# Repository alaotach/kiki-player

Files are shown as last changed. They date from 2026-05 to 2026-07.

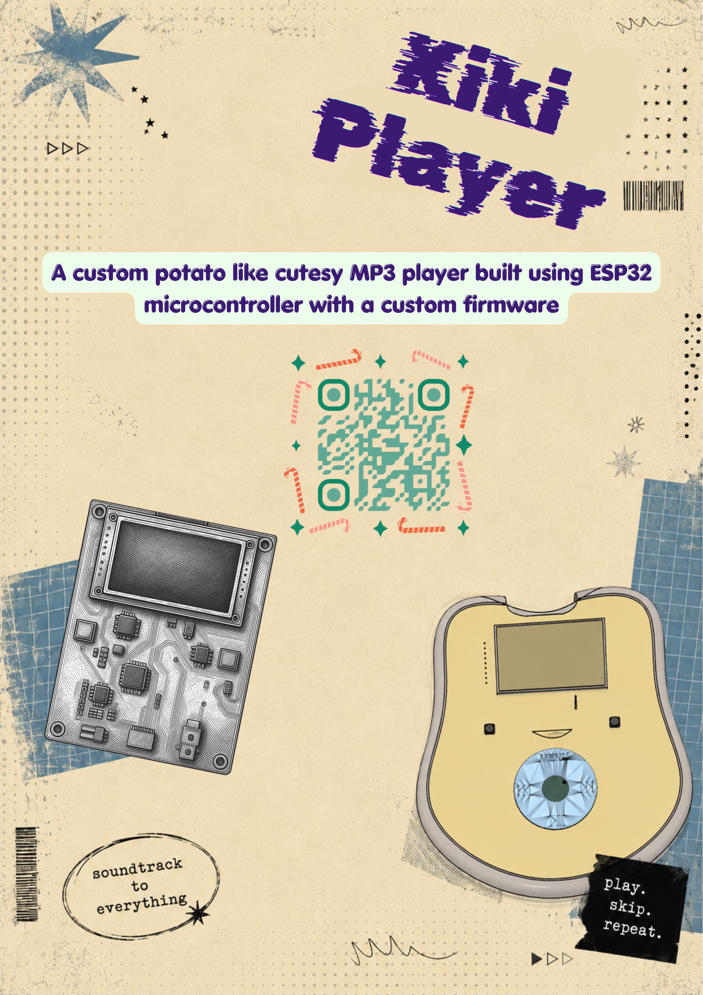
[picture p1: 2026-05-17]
docs/Blue and Pink Modern Film Poster.png

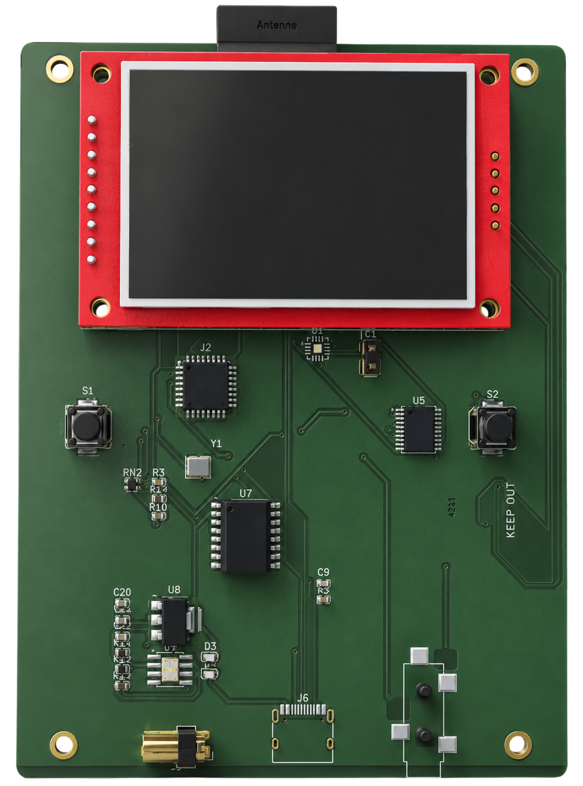
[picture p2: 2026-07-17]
assets/pcb-render.png.png

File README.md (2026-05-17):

# Kiki-Player

## Project Overview

So basically this whole thing was built for a program by hackclub named fallout and I got an idea to build an mp3 player to replace spotify like good old times from a random youtube video titled "how to quit spotify" and I actually managed to pull it off. It's a fully custom PCB including a 3D case that plays music, has a touch sensitive click wheel.

Zine

## What's Inside This Folder

**PCB Files:**
- `kiki-player.kicad_sch` - The main schematic where everything's connected.
- `kiki-player.kicad_pcb` - The actual PCB layout with all components placed and routed.
- `Sample-BOM_JLCSMT.xlsx` - Bill of Materials with all the parts.

**Firmware:**
- `kiki-player/` - It has all the firmware source code written in arduino with platformIo.

**3D Case Files:**
- `kiki-player-B_Cu.glb` / `kiki-player-B_Mask.glb` / `kiki-player-F_CuGlr` etc. - These are the individual layer exports from KiCad.
- `updated-pcb.step` - The 3D model of the PCB itself that I imported into Fusion 360 to design the case around it
- `kiki-player-case.stl` - The 3D model of the PCB case.

**Misc Files:**
- `.gorjob` files - Job queue files from Fusion 360 (not super important)
- `.csv` files - Component positioning data and BOM exports

## The Files You Actually Need

**To Manufacture the PCB:**
1. `kiki-player.kicad_pcb` - Send this to JLCPCB (export as gerbers first)
2. `Sample-BOM_JLCSMT.xlsx` - Upload this with your PCB order for parts + assembly
3. `kiki-player.kicad_sch` - Reference schematic if anything goes wrong

**For Reference:**
- `kiki-player.kicad_pro` - Open this in KiCad if you want to modify anything
- Schematic files - Check these if you want to understand how everything's wired

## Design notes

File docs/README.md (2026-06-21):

# Kiki-Player
## Project Overview
So basically this whole thing was built for a program by hackclub named fallout and I got an idea to build an mp3 player to replace spotify like good old times from a random youtube video titled "how to quit spotify" and I actually managed to pull it off. It's a fully custom PCB including a 3D case that plays music, has a touch sensitive click wheel.
zine-kikii

## What's Inside This Folder
**PCB Files:**
- `kiki-player.kicad_sch` - The main schematic where everything's connected.
- `kiki-player.kicad_pcb` - The actual PCB layout with all components placed and routed.
- `Sample-BOM_JLCSMT.xlsx` - Bill of Materials with all the parts.

**Firmware:**
- `kiki-player/` - It has all the firmware source code written in arduino with platformIo.

**3D Case Files:**
- `kiki-player-B_Cu.glb` / `kiki-player-B_Mask.glb` / `kiki-player-F_CuGlr` etc. - These are the individual layer exports from KiCad.
- `pcb.step` - The 3D model of the PCB itself that I imported into Fusion 360 to design the case around it
- 
- `kiki-player-case.step` - The 3D model of the PCB case.
kiki-case-1
kiki-case-2

**Misc Files:**
- `.csv` files - Component positioning data and BOM exports
- 

## The Files You Actually Need
**To Manufacture the PCB:**
1. `kiki-player.kicad_pcb` - Send this to JLCPCB
2. `Sample-BOM_JLCSMT.xlsx` - Upload this with your PCB order for parts + assembly
3. `kiki-player.kicad_sch` - Reference schematic if anything goes wrong

**For Reference:**
- `kiki-player.kicad_pro` - Open this in KiCad if you want to modify anything
---

## Build Guide

### Step 1 - Export Gerbers from KiCad

open `kiki-player.kicad_pcb` in KiCad, then go to **File → Fabrication Outputs → Gerbers**. In the dialog, make sure all layers are checked and hit Generate. Then go back to **File → Fabrication Outputs → Drill Files** and generate those too. Put everything in one folder and zip it up.

---

### Step 2 - Order the PCB from JLCPCB

Go to jlcpcb and upload your gerber zip.

- Then enable PCBA and upload `Sample-BOM_JLCSMT.xlsx` as the BOM and `kiki-player-all-pos.csv` as the component placement file.
---

### Step 3 - Prepare the SD Card

Format a MicroSD card as FAT32 and dump MP3 files into it.

---

### Step 4 - Solder the TH Parts

- **J5** - 2-pin JST PH2.0 MALE Connector - connects to battery lipo
- **LS1** - 2-pin JST PH2.0 MALE Connector - connects to speaker
- **J3** - 3.5mm audio jack
---

### Step 5 - Connect the Battery

Get a 1000mAh flat LiPo with a 2-pin JST PH2.0 connector.
---

### Step 6 - Connect the Display

- The ILI9341 display module connects via a ribbon cable.
---

### Step 7 - Flash the Firmware

```bash
cd firmware/kiki-player
pio run --target upload
```
( You need VSCode and PlatformIO for it )

### Step 8 - 3D Print and Assemble the Case
- **Material:** PLA works fine.

When everything fits, seat the PCB, connect the display ribbon, tuck the battery into the remaining space, and close the case.

---

## Modifying the Firmware

All config parameters live in:

```
firmware/kiki-player/include/Config.h
```

Features are split into modules under `firmware/kiki-player/src/`.

---

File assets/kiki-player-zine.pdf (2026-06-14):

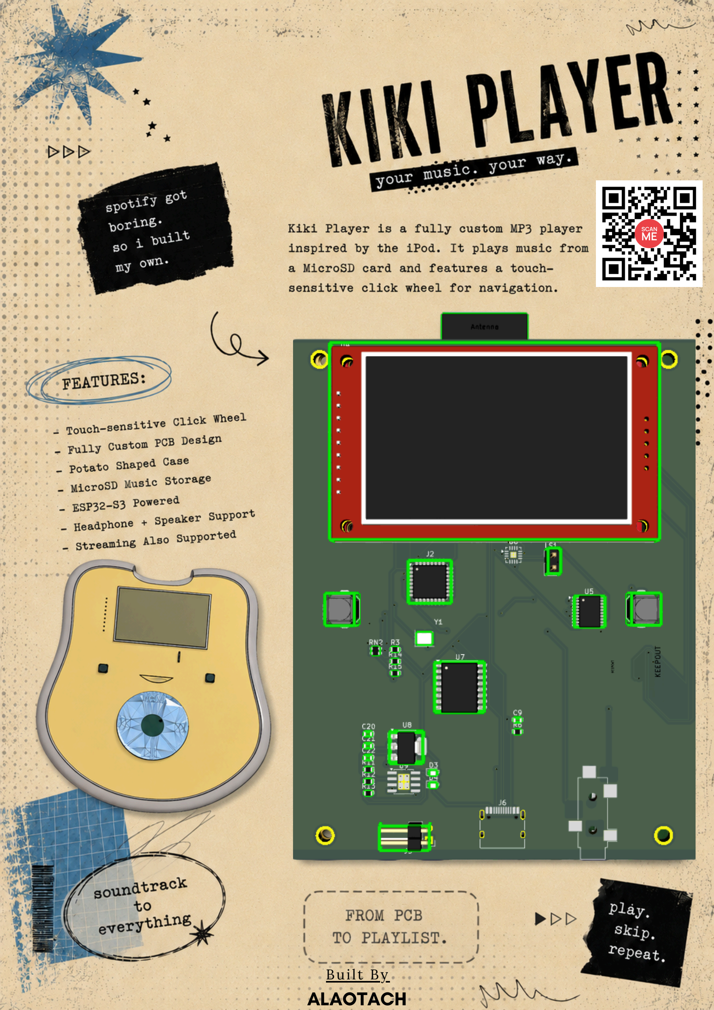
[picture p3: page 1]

Built By

### ALAOTACH

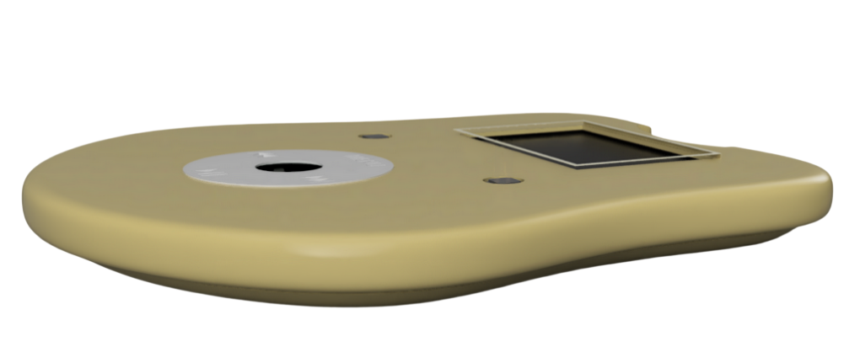
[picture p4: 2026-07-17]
assets/kiki-case-2.png

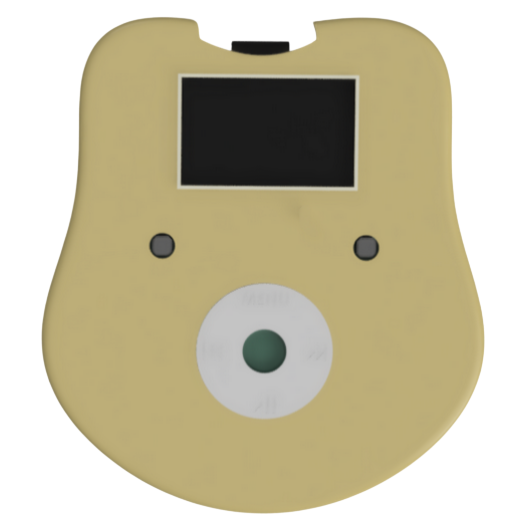
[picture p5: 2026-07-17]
assets/kiki-case-1.png

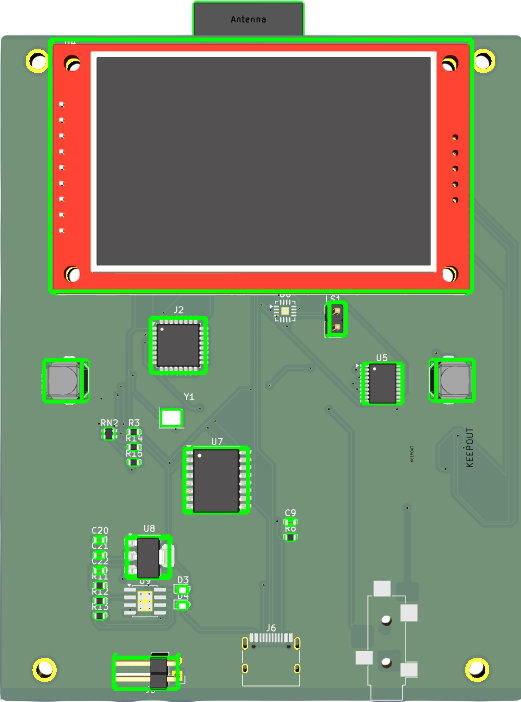
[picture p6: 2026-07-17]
assets/593719795-7c7b27b4-e8d0-4516-8f25-94fe95661591-Photoroom.png

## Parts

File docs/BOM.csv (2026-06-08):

Comment | Designator | Footprint | Qty | Unit Price | Total Price | URL
100nF | C21, C9, C18, C19, C17, C16 | Capacitor_SMD:C_603_1608Metric | 6.0 | 0.16 | 0.16 | https://quartzcomponents.com/products/100nf-0-1uf-104-50v-1206-smd-capacitor-pack-of-10-pieces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
10uF | C20, C22, C14, C15, C13, C12 | Capacitor_SMD:C_603_1608Metric | 6.0 | 0.16 | 0.32 | https://quartzcomponents.com/products/10uf-10000nf-50v-0805-x7r-smd-capacitor-pack-of-5-pieces
5.1k Ohm | R5, R4 | Resistor_SMD:R_0603_1608Metric | 2.0 | 0.084 | 0.084 | https://quartzcomponents.com/products/5-1k-ohm-1-4-watt-resistor-with-1-tolerance-pack-of-10
10k Ohm | R13, R6, R3, R14 | Resistor_SMD:R_0603_1608Metric | 4.0 | 0.15 | 0.15 | https://quartzcomponents.com/products/10k-ohm-2-watt-resistor
100k Ohm | R14, R15 | Resistor_SMD:R_0603_1608Metric | 2.0 | 0.08 | 0.08 | https://quartzcomponents.com/products/100k-ohm-0603-package-1-10w-smd-resistor-5-tolerance-pack-of-20-pieces
PCM5102A | U5 | Package_SO:TSSOP-20_4.4x6.5mm_P0.65mm | 1.0 | 1.84 | 1.84 | https://robu.in/product/weact-studio-i2s-speaker-module-pcm5100a/?gad_source=1&gad_campaignid=17416544847
DS3231M | U7 | Package_SO:SOIC-16W_7.5x10.3mm_P1.27mm | 1.0 | 1.76 | 1.76 | https://www.electropi.in/ds3231-rtc-module-india?gad_source=1&gad_campaignid=23329895947
SW_PUSH | SW3, SW4 | Button_Switch_SMD:SW_Push_1TS009xxxx-xxxx-xxxx_6x6x5mm | 2.0 | 0.038 | 0.076 | https://www.electropi.in/push-button-switch-2-pin-5mm?gad_source=1&gad_campaignid=23329895947
Speaker | LS1 | Connector_PinHeader_2.54mm:PinHeader_1x02_p2.54mm_Vertical | 1.0 | 1.58 | 1.58 | https://www.amazon.in/Electronic-Spices-Power-Woofer-Speaker/dp/B0BN44HPF9
MGC3130-I/MQ | J2 | Package_QFP:TQFP-32_7x7mm_P0.8mm | 1.0 |  | 1.0
MAX98357A | U6 | Package_DFN_QFN:TQFN-16-1EP_3x3mm_P0.5mm_EP1.23x1.23mm | 1.0 | 4.68 | 4.68 | https://www.amazon.in/Oceanlabz-MAX98357A-Amplifier-Microphone-Raspberry/dp/B0GT4N822M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
AudioPlug3 | J3 | Connector_Audio:Jack_3.5mm_CUI_SJ-3524-SMT_Horizontal | 1.0 | 0.13 | 0.13 | https://robu.in/product/audio-jack-pj311-3-5mm-female-connector-black/?gad_source=1&gad_campaignid=17427802703
Conn_02x01 | J5 | Connector_PinHeader_2.54mm:PinHeader_1x02_p2.54mm_Horizontal | 1.0 |  | 1.0
AMS1117-3.3 | U8 | Package_TO_SOT_SMD:SOT-223-3_TabPin2 | 1.0 | 0.073 | 0.073 | https://robu.in/product/ams1117-3-3v-1a-sot-223-voltage-regulator-ic-pack-of-5-ics/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
TP4056-42-ESOP8 | U9 | Package_SO:SOIC-8-1EP_3.9x4.9mm_P1.27mm_EP2.41x3.3mm_ThermalVias | 1.0 | 0.33 | 0.33 | https://robu.in/product/tp4056-1a-li-ion-battery-charging-board-micro-usb-with-current-protection-type-c-connector/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
LED | D3, D4 | LED_SMD:LED_0603_1608Metric | 2.0 | 0.01 | 0.02
CR2013-MI2120 | U4 | Display:CR2013-MI2120 | 1.0 | 2.6 | 2.6 | https://www.electropi.in/1.8-inch-tft-lcd-module-128x160-with-4-io
ESP32-S3-WROOM-1 | U1 | RF_Module:ESP32-s3-WROOM-1 | 1.0 | 3.86 | 3.86 | https://www.electropi.in/espressif-esp32-s3-wroom-1-n4r8-modules?gad_source=1&gad_campaignid=23329895947
Crystal | Y1 | Crystal:Crystal_SMD_3225-4Pin_3.2x2.5mm | 1.0 | 0.22 | 0.22 | https://robu.in/product/ysx321sl-24mhz-12pf-10ppm-4pins-smd-smt-metal-surface-quartz-crystal-pack-of-2/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
1.2k Ohm | R11, R12 | Resistor_SMD:R_0603_1608Metric | 2.0 | 0.01 | 0.02
Voltage Devider | RN2 | Resistor_SMD:R_Array_Convex_2x0603 | 1.0 | 0.01 | 0.01
12pF | C7, C8 | Capacitor_SMD:C_603_1608Metric | 2.0 | 0.01 | 0.02
1000 mAh battery |  |  | 1.0 | 4.2 | 4.2 | https://robu.in/product/wly394058-1000mah-3-7v-single-cell-rechargeable-lipo-battery/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
TOTAL |  |  |  |  | 24.231

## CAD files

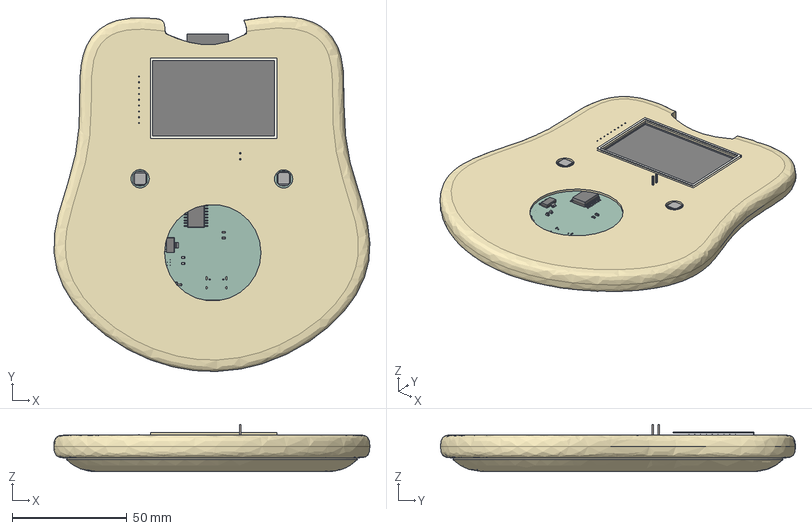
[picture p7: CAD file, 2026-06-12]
cad/kiki-player-case.step
137.5 x 154.5 x 20.6 mm
C_0603_1608Metric x 14
TQFP-32_7x7mm_P0.8mm
Crystal_SMD_3225-4Pin_3.2x2.5mm
CR2013-MI2120
SOT-223
R_0603_1608Metric x 9
LED_0603_1608Metric x 2
TSSOP-20_4.4x6.5mm_P0.65mm
pin_1 x 2
pin_2 x 2
PinHeader_1x02_P2.54mm_Horizontal
SOIC-16W_7.5x10.3mm_P1.27mm
PinHeader_1x02_P2.54mm_Vertical
R_Array_Convex_2x0603
ESP32-S3-WROOM-1
microSD_HC_Hirose_DM3D-SF
kiki-player_PCB

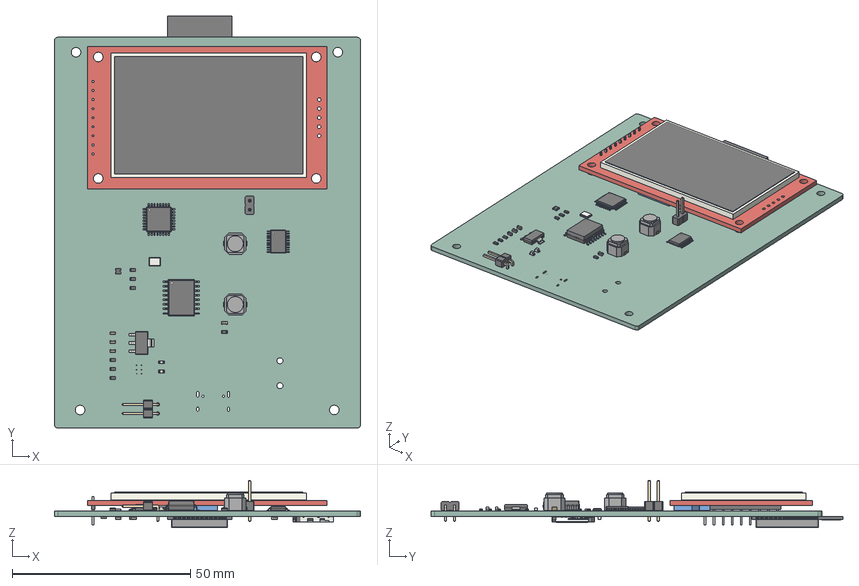
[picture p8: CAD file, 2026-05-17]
cad/kiki-pcb.step
86.0 x 115.7 x 13.3 mm
C_0603_1608Metric x 14
TQFP-32_7x7mm_P0.8mm
Crystal_SMD_3225-4Pin_3.2x2.5mm
CR2013-MI2120
SOT-223
R_0603_1608Metric x 9
LED_0603_1608Metric x 2
TSSOP-20_4.4x6.5mm_P0.65mm
pin_1 x 2
pin_2 x 2
PinHeader_1x02_P2.54mm_Horizontal
SOIC-16W_7.5x10.3mm_P1.27mm
PinHeader_1x02_P2.54mm_Vertical
R_Array_Convex_2x0603
ESP32-S3-WROOM-1
microSD_HC_Hirose_DM3D-SF
kiki-player_PCB

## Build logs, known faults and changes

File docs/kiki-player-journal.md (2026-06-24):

# Kiki Player — Journal Export

- Exported at: 2026-06-24T16:08:42Z
- Project ID: 2789
- Entries: 18

## Entry 1
- ID: 4595
- Author: AlAoTach
- Created At: 2026-04-30T07:27:17Z

### Content

so in this timelapse i just started building the project schematic using kicad, It's my first time doing it on kicad i have built multiple irl hardware projects but yeah never a schematic so it was just a bit confusing to me so i am trying to learn it.



### Recording Links

- https://public.lapse-hackclub.link/timelapses/h5YQ-Y8bUIKa/timelapse-h5YQ-Y8bUIKa.mp4

## Entry 2
- ID: 4820
- Author: AlAoTach
- Created At: 2026-05-01T20:58:30Z

### Content

fixed the connection because i got to know one capacitor wont be able to handle all the vdd connections and then i added c type charging connection and then the charging ic 



### Recording Links

- https://lookout.hackclub.com/api/media/8448b76b-9b0b-4c94-bdef-9e5df04b1a6c/video.mp4

## Entry 3
- ID: 5171
- Author: AlAoTach
- Created At: 2026-05-02T20:11:59Z

### Content

setting the connections of the ILI9341 LCD display for the mp3 player screen, and got to know that i can use labels to make connections instead of using actual long wires




### Recording Links

- https://public.lapse-hackclub.link/timelapses/e0RJr06cIz37/timelapse-e0RJr06cIz37.mp4

## Entry 4
- ID: 5173
- Author: AlAoTach
- Created At: 2026-05-02T20:16:46Z

### Content

I was searching for the IC mgc3130 for the mp3 player touch joystick thingy because i found ipod uses the same IC so i tried to find the symbol of it but i could not i found the footprint but not symbol so i used a connector of 28 pins instead which i will replace later on JLCPCB while building 



### Recording Links

- https://public.lapse-hackclub.link/timelapses/td17E7rtOMFY/timelapse-td17E7rtOMFY.mp4

## Entry 5
- ID: 5174
- Author: AlAoTach
- Created At: 2026-05-02T20:22:04Z

### Content

finished the schema by adding headphone jack and speaker connections and an sd card slot for music to be stored but i didnt know that the not connected pins can cause a problem and some power issue i got between input and output pins so it required me to use the power flags i added them wherever the pointer was but i still dont know much about it 
Screenshot 2026-05-03 013633.png

### Recording Links

- https://public.lapse-hackclub.link/timelapses/noo1JiTq9g_K/timelapse-noo1JiTq9g_K.mp4

## Entry 6
- ID: 5175
- Author: AlAoTach
- Created At: 2026-05-02T20:25:28Z

### Content

fixed all the errors and warnings in this one first and then i learnt how to like do the footprints thing and then assigned the footprints to all the symbols which didnt have it and completed the schema so now i can move on to the pcb ig i will clean the schema later idk if i can do that or not so i will reasearch about it too





### Recording Links

- https://public.lapse-hackclub.link/timelapses/UZmazvyCxhB8/timelapse-UZmazvyCxhB8.mp4

## Entry 7
- ID: 5921
- Author: AlAoTach
- Created At: 2026-05-07T16:56:04Z

### Content

I have never done the pcb designing so i had no idea how to even make via or even place wires like lol i was thinking that the blue wires it was showing were the actual wires i didnt know that i had to place actual copper wires too but later my friend told me that then i realized my designed is so fked up and the wires are all stragling together i dont know how i will clean all this mess but i watched few pcb design videos of kicad tutorials and learned how to place vias and wires and started cleaning up the pcb first by minimizing the blue wires but in between when it was looking kinda good my kicad crashed and i lost the process and i had to start fresh which i did and started cleaning up again and it is not looking good yet still stragled i am trying out things but nothing was helping so i started placing copper wires to see if they might help me maybe later it gets cleaned by itself it might be a very stupid decision but i dont know what to do at this point so i'll give it a shot







### Recording Links

- https://public.lapse-hackclub.link/timelapses/anXocboqdUuH/timelapse-anXocboqdUuH.mp4
- https://public.lapse-hackclub.link/timelapses/tXRPGQ3ZReVo/timelapse-tXRPGQ3ZReVo.mp4

## Entry 8
- ID: 7278
- Author: AlAoTach
- Created At: 2026-05-15T16:16:42Z

### Content

in this timelapse i was trying to fix the pcb component placements so i can minimize the connections and also distance and placement of wires so that i can route them easily because i tried routing them before but it was not possible to route them like that so later i even asked my senior if he can suggest something to me he said that placing the capacitors nearby and using a ground plane might help alot which kind of did help but not really because the components were so cluttered now i am researching how i can fix this mess that i have created



### Recording Links

- https://public.lapse-hackclub.link/timelapses/XuGwHXXurPTZ/timelapse-XuGwHXXurPTZ.mp4

## Entry 9
- ID: 7289
- Author: AlAoTach
- Created At: 2026-05-15T17:28:11Z

### Content

this session was absolutely wild I started working on the pcb routing around 6pm thinking I'd knock out the component placement and maybe get some traces done but 4 hours later i realized that I built entire circuit around the wrong microcontroller footprint the routing had become this impossible mess of lines crossing over each other like noodles lol and I was genuinely starting to panic that i just didnt wanted to continue on this but it was my first pcb and it was just 2 layer pcb too i had started to consider increasing the pcb layers but idk i thought it'd become more hard then cuz there was just no way I could fit all those signal paths on a board ts small tho... so I just kept staring at the kicad watching these crossing traces and thinking this project is dead lol and I was just frustrated as hell cuz i was trying to fix it for days now then I decided to read some routing tutorials and research things about it instead of just guessing and that's when it hit me that the esp symbol in my schematic wasn't the full dev board i knew it was just the qfn chip but still like i thought it'd be fine but it wasnt esp devboard was much better and instead of strangling so much i could actually fix the connections too by using the pins of correct sides instead of random pins that is what i did after that and suddenly things started making sense and thats when I also discovered feature in kicad called hierarchy from which you can organize ur schematic into logical groups and it automatically helps with pcb placement and routing so I spent the next few hours creating hierarchical structure the esp dev board in the center top because it had an antenna too on the back side of the tft display.... once I had that structure in place the actual repositioning of components became almost trivial I just moved things to cluster with their functional groups and the board layout finally started to look kinda professional... I only recorded four hours of this session but the whole thing took about eight hours and honestly every single minute was worth it cuz by the end my pcb became routable....I'm exhausted but also kind of euphoric cuz I learned smtg alot abt pcb design and it's not just about fitting components on a board my eyes and head is actually hurting from staring at the screen but I finally feel like this project is actually going to work....













### Recording Links

- https://public.lapse-hackclub.link/timelapses/00CKbVBkcYF_/timelapse-00CKbVBkcYF_.mp4
- https://public.lapse-hackclub.link/timelapses/YBXaT5z2tPYH/timelapse-YBXaT5z2tPYH.mp4
- https://public.lapse-hackclub.link/timelapses/F8gkgZKHWC7Q/timelapse-F8gkgZKHWC7Q.mp4

## Entry 10
- ID: 7309
- Author: AlAoTach
- Created At: 2026-05-15T19:18:23Z

### Content

I ran into a footprint issue idk why for the 29N connector socket which idk why wasnt fixing but after restarting kicad and reuploading the library of the footprint i got it working and then i forgot to start the recording and fixed the layout off camera accidentally 



### Recording Links

- https://public.lapse-hackclub.link/timelapses/a_NMBJeQgoNa/timelapse-a_NMBJeQgoNa.mp4

## Entry 11
- ID: 7310
- Author: AlAoTach
- Created At: 2026-05-15T19:25:41Z

### Content

now i have started doing the routing which seemed to be pretty simple at start and this time i was doing it very carefully too and i have learned how to do vias and all so i was using them intelligently too





### Recording Links

- https://public.lapse-hackclub.link/timelapses/a6P7VrWP4V44/timelapse-a6P7VrWP4V44.mp4
- https://public.lapse-hackclub.link/timelapses/_wN5mlHJVe_4/timelapse-_wN5mlHJVe_4.mp4

## Entry 12
- ID: 7311
- Author: AlAoTach
- Created At: 2026-05-15T19:39:34Z

### Content

im not sure this one will play or not because there was some error on the lapse in this one but it is showing here so i am creating this journal for this and in this one too i was doing only the routing nothing really special 



## Entry 13
- ID: 7314
- Author: AlAoTach
- Created At: 2026-05-15T19:47:14Z

### Content

in last timelapse my pcb was done so in this one i have started to export the pcb for print but there were some issues like some sort of violation issue and it was because of 2 wires being very near lol so it took me some time to figure out but i fixed it then it was ready to be exported and i didnt know how to even export it so i looked up the internet and exported it and uploaded to jlcpcb and then they asked me for BOM so i created that and also a components position list i uploaded that too and then it was finally done and ready to be printed 




### Recording Links

- https://public.lapse-hackclub.link/timelapses/H7rlU8RbZF2g/timelapse-H7rlU8RbZF2g.mp4

## Entry 14
- ID: 7319
- Author: AlAoTach
- Created At: 2026-05-15T20:03:26Z

### Content

In these timelapses i have designed the case of the pcb in fusion 360 first i didnt even knew how do i get my pcb into it and then when i got to know about upload i tried so many times but it was not uploading and getting stucked at uploading i tried with vpn without vpn everything but still not uploading then i tried using the web version of fusion 360 and there my pcb got uploaded and i started making the design then after designing a bit i realized placement of my buttons is not right so i had to fix it in pcb then reupload and then i did it and it created a new file for that so i had to copy the body and sketch of the case i created from one to another which i did but at first it didnt work correctly with the surface thing it was covering everything including the screen and buttons but before it left them so i started designing the spline again but i was not able to make the same shape again it was getting weird so again i tried copying the spline and pasting directly after reading some articles on this on their forums which were saying do ctrl c ctrl v and it worked for them so again i treid and this time it worked perfectly which saved alot of my time then i continued designing using a reference of a potato a cute one but it ended up being something else but it is still so cute i like it i also added ipod button 3d model in it and then created the backside split it and learned alot about fusion 360 i would have done things more better if i had watched few videos about it but i hate watching tutorials and love doing it on my own always so i did that only and learned while doing it about the tools fusion has like i created the bump and all at the back myself and it was pretty much fun it's better than blender when it comes to make some sort of cases and all much better than blender im sure i wont be able to make even a design like this in blender and now my design for the pcb is done finally i have to create only a BOM for fallout then i can submit it for review so excited to go to the hackathon and meet y'all

Screenshot 2026-05-14 212301.png

Screenshot 2026-05-14 234054.png

Screenshot 2026-05-15 163045.png
Screenshot 2026-05-15 212245.png
Screenshot 2026-05-16 003037.png
Screenshot 2026-05-16 003049.png
<!-- Uploading Screenshot 2026-05-16 003106.png (131 KB)... Processing... -->

### Recording Links

- https://public.lapse-hackclub.link/timelapses/R57Hp50KPia1/timelapse-R57Hp50KPia1.mp4
- https://public.lapse-hackclub.link/timelapses/SZKaKrqgl1Eh/timelapse-SZKaKrqgl1Eh.mp4
- https://public.lapse-hackclub.link/timelapses/Cn461WXIvGLI/timelapse-Cn461WXIvGLI.mp4
- https://public.lapse-hackclub.link/timelapses/_gUbNGkScORg/timelapse-_gUbNGkScORg.mp4
- https://public.lapse-hackclub.link/timelapses/dfEhbaHNIjbD/timelapse-dfEhbaHNIjbD.mp4

## Entry 15
- ID: 7328
- Author: AlAoTach
- Created At: 2026-05-15T21:03:26Z

### Content

Creating the BOM of the pcb according to the fallout requirements i updated the old BOM i had created for jlcpcb with link and price.



### Recording Links

- https://public.lapse-hackclub.link/timelapses/quyWRcunbZpT/timelapse-quyWRcunbZpT.mp4

## Entry 16
- ID: 7604
- Author: AlAoTach
- Created At: 2026-05-17T13:05:23Z

### Content

After hardware design part was done i thought i can submit the project now and i will do the firmware part later but while submitting i got the popup that 95% rejection happen by these small mistakes and there it was mentioned that i'd need the firmware done too if my hardware requires one and it obviously does so i started working on it after some time because i had gotten sad that i can't submit it rn and firmware is the most boring part to make in a hardware project tbh and that too when you can't test it, it becomes even more boring but still i started working on it so first i wrote all the pins i had connected to esp in a header file and then the config file in which i defined some variables like screen dimensions, audio sample rates, battery thresholds, all that stuff then I started with the drivers one by one first rtc with fallback to millis if the hardware wasn't there, battery monitoring with adc voltage divider math and charging detection from the TP4056, button debouncing with proper state machines for detecting long presses, the MGC3130 wheel communication over i2c with wraparound handling for the circular position, SD card scanning recursively through folders to find all the MP3s, TFT display initialization with backlight PWM, then the audio system MP3 playback with volume control, next/prev track navigation with shuffle and repeat modes etc.  after all that came the ui which was the most easiest part lol cuz i already knew what parts to create in ui scrollable menus, player screen with progress bar. then main.cpp tying everything together with proper boot sequence and the main loop handling input, audio ticking, battery checks, screen refreshes, idle detection, and deep sleep after 5 minutes of inactivity. now it's all done the firmware is pretty minimal right not exactly like ipod and all which i had thought i'd make but yeah it's nice and working atleast so it's fine yeah I can't test any of it, but that's fine ig in a few weeks when the PCB gets fabricated everything will be fixed haha...

Screenshot 2026-05-17 175824.png

### Recording Links

- https://public.lapse-hackclub.link/timelapses/1M6aCfPT2IGm/timelapse-1M6aCfPT2IGm.mp4
- https://public.lapse-hackclub.link/timelapses/kgmCzgB9UcES/timelapse-kgmCzgB9UcES.mp4
- https://public.lapse-hackclub.link/timelapses/t_YMRMmywb-v/timelapse-t_YMRMmywb-v.mp4
- https://public.lapse-hackclub.link/timelapses/_Kg9aZhKMZq8/timelapse-_Kg9aZhKMZq8.mp4
- https://public.lapse-hackclub.link/timelapses/s4RG_706poc9/timelapse-s4RG_706poc9.mp4
- https://public.lapse-hackclub.link/timelapses/Imjk_bCfukYz/timelapse-Imjk_bCfukYz.mp4
- https://public.lapse-hackclub.link/timelapses/LEUWW4uYj64w/timelapse-LEUWW4uYj64w.mp4
- https://public.lapse-hackclub.link/timelapses/3aEWu09qkfIJ/timelapse-3aEWu09qkfIJ.mp4
- https://public.lapse-hackclub.link/timelapses/zqx7SHXv6LRd/timelapse-zqx7SHXv6LRd.mp4

## Entry 17
- ID: 7606
- Author: AlAoTach
- Created At: 2026-05-17T13:07:26Z

### Content

and finally before submitting the zine timelapse on guide it was suggested to use figma which i did gave a try but i had never used figma and i knew canva very well so i made the zine on canva by picking a nice template it doesnt look very fascinating but it's decent and good 
Screenshot 2026-05-17 175824.png

### Recording Links

- https://public.lapse-hackclub.link/timelapses/Q2tP2bpgDej2/timelapse-Q2tP2bpgDej2.mp4
- https://public.lapse-hackclub.link/timelapses/B75PApBQHXwI/timelapse-B75PApBQHXwI.mp4

## Entry 18
- ID: 9601
- Author: AlAoTach
- Created At: 2026-05-27T07:55:59Z

### Content

fixed the requirements check issues first fixed the BOM link issue, replaced the non working links ( which were working for me somehow but not fallout ) then fixed the schema as suggested i grouped the components so it looks visually more better and also fixed the issues in the hierarchical schemas and added decoupling wherever needed and fixed all the ERC warnings
Screenshot 2026-05-27 120730.png
Screenshot 2026-05-27 121105.png

### Recording Links

- https://public.lapse-hackclub.link/timelapses/OQI7hDXunukB/timelapse-OQI7hDXunukB.mp4

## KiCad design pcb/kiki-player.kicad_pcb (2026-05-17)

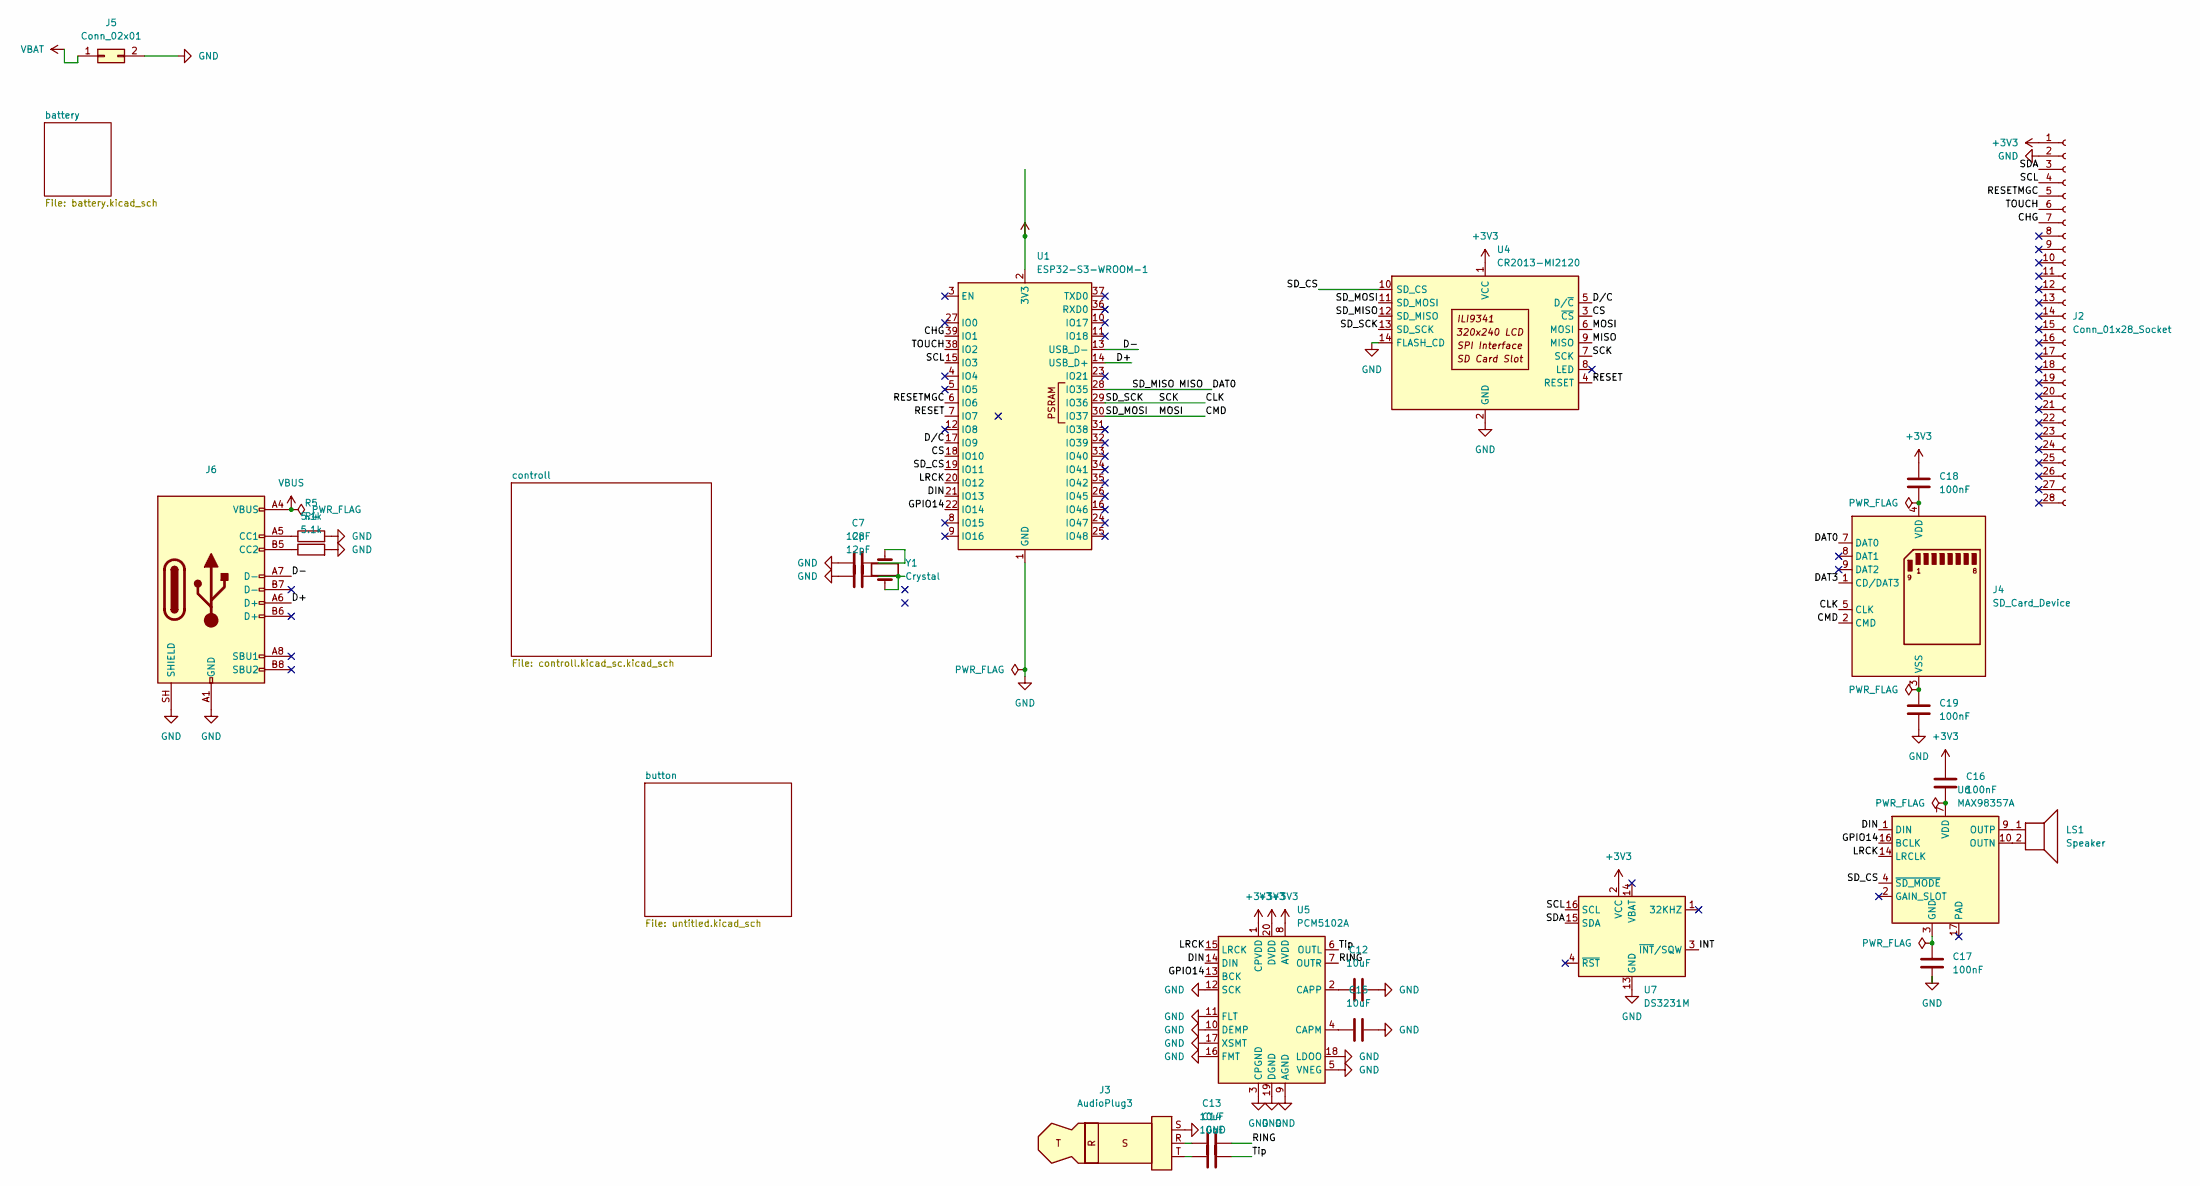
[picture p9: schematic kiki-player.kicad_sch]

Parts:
C7, C8: 12pF; C_0603_1608Metric
C12, C13, C14, C15: 10uF; C_0603_1608Metric
C16, C17, C18, C19: 100nF; C_0603_1608Metric
J2: Conn_01x28_Socket; TQFP-32_7x7mm_P0.8mm
J3: AudioPlug3; Jack_3.5mm_CUI_SJ-3524-SMT_Horizontal
J4: SD_Card_Device; microSD_HC_Hirose_DM3D-SF
J5: Conn_02x01; PinHeader_1x02_P2.54mm_Horizontal
J6: USB_C_Receptacle_USB2.0_16P; USB_C_Receptacle_HRO_TYPE-C-31-M-12
LS1: Speaker; PinHeader_1x02_P2.54mm_Vertical
R4, R5: 5.1k; R_0603_1608Metric
U1: ESP32-S3-WROOM-1
U4: CR2013-MI2120
U5: PCM5102A; TSSOP-20_4.4x6.5mm_P0.65mm
U6: MAX98357A; TQFN-16-1EP_3x3mm_P0.5mm_EP1.23x1.23mm
U7: DS3231M; SOIC-16W_7.5x10.3mm_P1.27mm
Y1: Crystal; Crystal_SMD_3225-4Pin_3.2x2.5mm

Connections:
+3V3: C16.1, C18.1, J2.1 (VDD), U1.2 (3V3), U4.1 (VCC), U5.1 (CPVDD), U5.8 (AVDD), U5.20 (DVDD), U7.2 (VCC); also elsewhere on the board
/CHG: J2.7 (CHG), U1.39 (IO1)
/CLK: J4.5 (CLK), U1.29 (IO36), U4.7 (SCK), U4.13 (SD_SCK)
/CMD: J4.2 (CMD), U1.30 (IO37), U4.6 (MOSI), U4.11 (SD_MOSI)
/CS: U1.18 (IO10), U4.3 (~CS)
/D+: J6.A6 (D+), U1.14 (USB_D+)
/D-: J6.A7 (D-), U1.13 (USB_D-)
/DAT0: J4.7 (DAT0), U1.28 (IO35), U4.9 (MISO), U4.12 (SD_MISO)
/DAT3: J4.1 (CD/DAT3)
/DIN: U1.21 (IO13), U5.14 (DIN), U6.1 (DIN)
/D/C: U1.17 (IO9), U4.5 (D/~C)
/GPIO14: U1.22 (IO14), U5.13 (BCK), U6.16 (BCLK)
/INT: U7.3 (~INT/SQW)
/LRCK: U1.20 (IO12), U5.15 (LRCK), U6.14 (LRCLK)
/RESET: U1.7 (IO7), U4.4 (RESET)
/RESETMGC: J2.5 (RESET), U1.6 (IO6)
/RING: C13.2, U5.7 (OUTR)
/SCL: J2.4 (SCL), U1.15 (IO3), U7.16 (SCL)
/SDA: J2.3 (SDA), U7.15 (SDA)
/SD_CS: U1.19 (IO11), U4.10 (SD_CS), U6.4 (~SD_MODE)
/TOUCH: J2.6 (TOUCH), U1.38 (IO2)
/Tip: C14.2, U5.6 (OUTL)
GND: C7.1, C8.1, C12.2, C15.2, C17.2, C19.2, J2.2 (GND), J3.S, J5.2, J6.A1 (GND), J6.A12 (GND), J6.B1 (GND), J6.B12 (GND), J6.SH (SHIELD), R4.2, R5.2, U1.1 (GND), U1.40 (GND), U1.41 (GND), U4.2 (GND), U4.14 (FLASH_CD), U5.3 (CPGND), U5.5 (VNEG), U5.9 (AGND), U5.10 (DEMP), U5.11 (FLT), U5.12 (SCK), U5.16 (FMT), U5.17 (XSMT), U5.18 (LDOO), U5.19 (DGND), U7.5 (GND), U7.6 (GND), U7.7 (GND), U7.8 (GND), U7.9 (GND), U7.10 (GND), U7.11 (GND), U7.12 (GND), U7.13 (GND); also elsewhere on the board
unnamed: C7.2, Y1.2
unnamed: C8.2, Y1.1
unnamed: C13.1, J3.R
unnamed: C14.1, J3.T
unnamed: C16.2, U6.7 (VDD), U6.8 (VDD)
unnamed: C17.1, U6.3 (GND), U6.11 (GND), U6.15 (GND)
unnamed: C19.1, J4.3 (VSS), J4.6 (VSS)
unnamed: C18.2, J4.4 (VDD)
unnamed: J6.A5 (CC1), R5.1
unnamed: J6.B5 (CC2), R4.1
unnamed: C15.1, U5.4 (CAPM)
unnamed: C12.1, U5.2 (CAPP)
unnamed: LS1.2, U6.10 (OUTN)
unnamed: LS1.1, U6.9 (OUTP)
VBAT: J5.1; also elsewhere on the board
VBUS: J6.A4 (VBUS), J6.A9 (VBUS), J6.B4 (VBUS), J6.B9 (VBUS); also elsewhere on the board

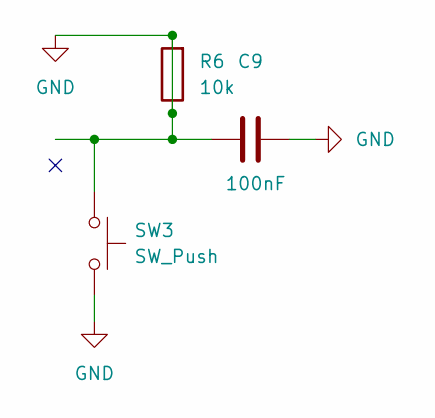
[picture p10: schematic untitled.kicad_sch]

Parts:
C9: 100nF; C_0603_1608Metric
R6: 10k; R_0603_1608Metric
SW3: SW_Push; SW_Push_1TS009xxxx-xxxx-xxxx_6x6x5mm

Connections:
GND: C9.1, C9.2, R6.1, R6.2, SW3.1, SW3.2; also elsewhere on the board

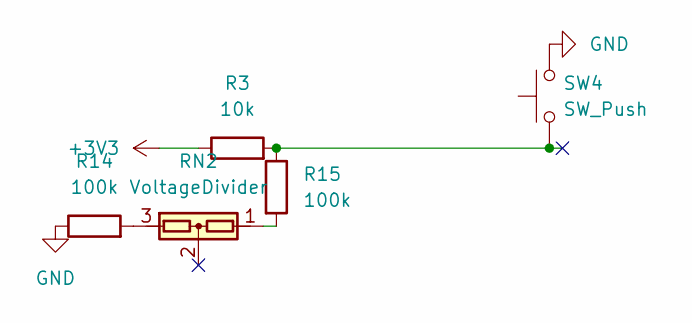
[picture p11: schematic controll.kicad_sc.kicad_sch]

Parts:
R3: 10k; R_0603_1608Metric
R14, R15: 100k; R_0603_1608Metric
RN2: VoltageDivider; R_Array_Convex_2x0603
SW4: SW_Push; SW_Push_1TS009xxxx-xxxx-xxxx_6x6x5mm

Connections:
+3V3: R3.1; also elsewhere on the board
GND: R14.1, SW4.2 (2_2); also elsewhere on the board
unnamed: R14.2, RN2.3
unnamed: R15.2, RN2.1

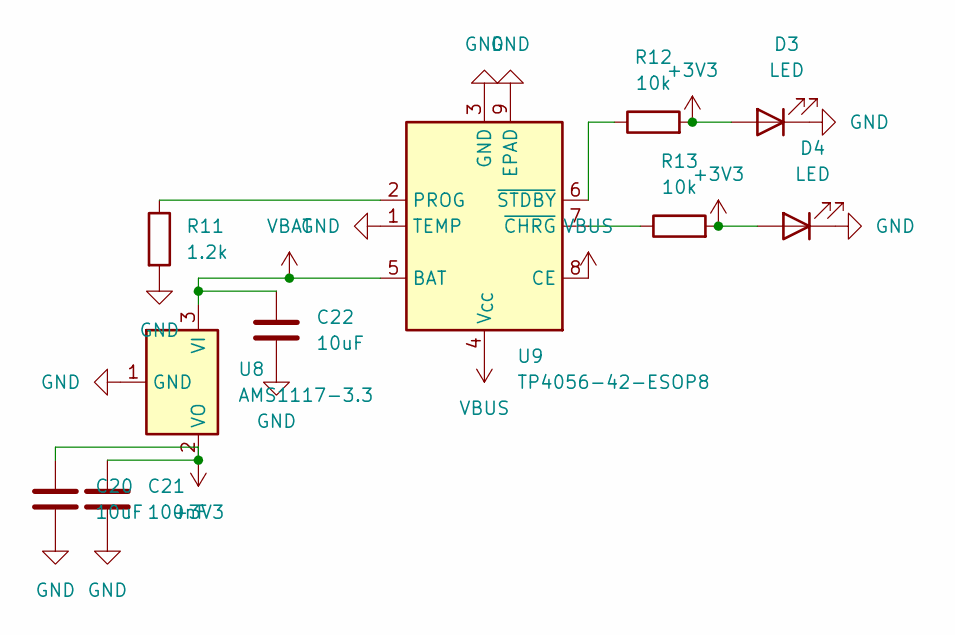
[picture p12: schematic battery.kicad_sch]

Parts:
C20, C22: 10uF; C_0603_1608Metric
C21: 100nF; C_0603_1608Metric
D3, D4: LED; LED_0603_1608Metric
R11: 1.2k; R_0603_1608Metric
R12, R13: 10k; R_0603_1608Metric
U8: AMS1117-3.3; SOT-223-3_TabPin2
U9: TP4056-42-ESOP8; SOIC-8-1EP_3.9x4.9mm_P1.27mm_EP2.41x3.3mm_ThermalVias

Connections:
+3V3: C20.1, C21.1, D3.2 (A), D4.2 (A), R12.2, R13.2, U8.2 (VO); also elsewhere on the board
GND: C20.2, C21.2, C22.2, D3.1 (K), D4.1 (K), R11.2, U8.1 (GND), U9.1 (TEMP), U9.3 (GND), U9.9 (EPAD); also elsewhere on the board
unnamed: R11.1, U9.2 (PROG)
unnamed: R13.1, U9.7 (~CHRG)
unnamed: R12.1, U9.6 (~STDBY)
VBAT: C22.1, U8.3 (VI), U9.5 (BAT); also elsewhere on the board
VBUS: U9.4 (V_{CC}), U9.8 (CE); also elsewhere on the board

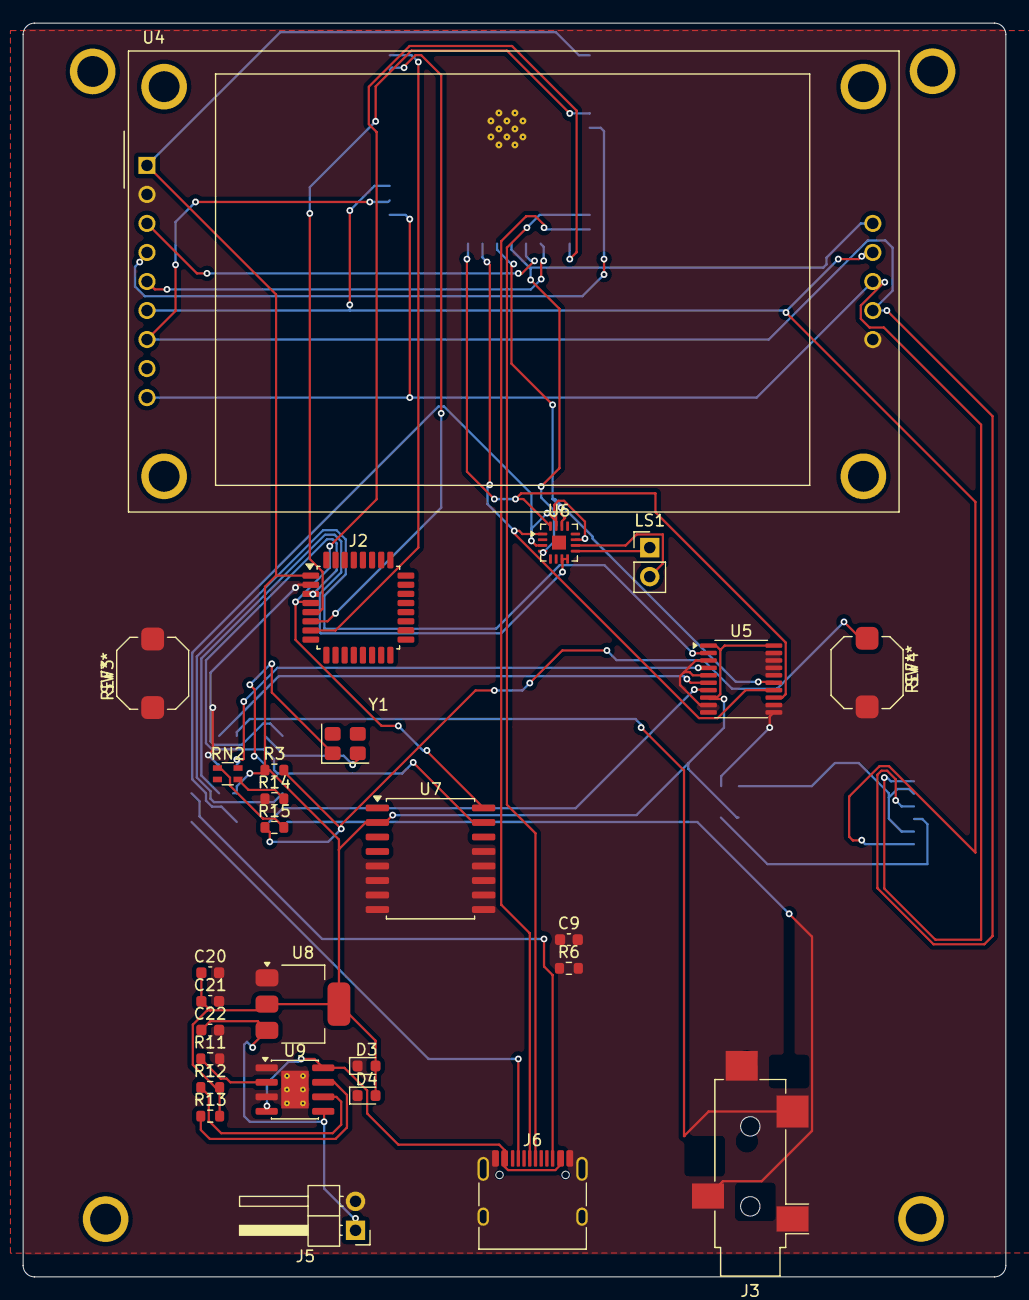
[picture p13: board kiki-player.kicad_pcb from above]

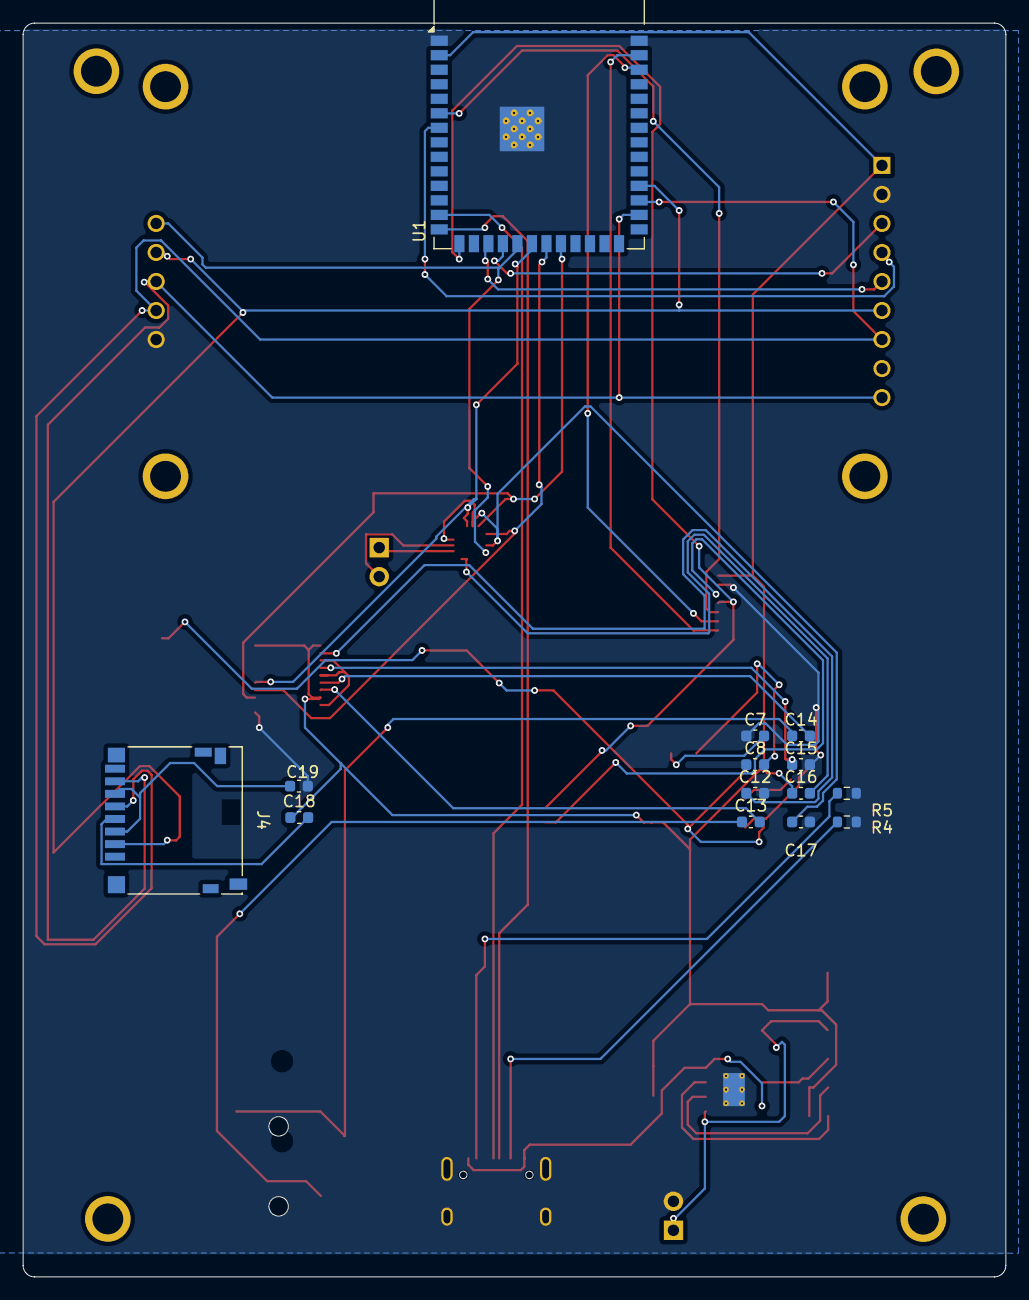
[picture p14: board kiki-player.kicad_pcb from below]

Board: 2 copper layers, 86.0 x 109.7 mm, 42 parts (14 on the bottom side), 42 nets.

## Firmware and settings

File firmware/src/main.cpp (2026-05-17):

#include <Arduino.h>
#include <pins.h>
#include <config.h>
#include <appState.h>
#include <audio.h>
#include <display.h>
#include <rtc.h>
#include <sdcard.h>
#include <ui.h>
#include <input.h>
#include <battery.h>

AppState appState= {
  Screen::HOME,
  RepeatModes::OFF,
  InputState::NONE,
  PlaybackState::STOPPED,
  BatteryStatus::FULL,
  VolumeLevel::MEDIUM,
  MenuItem::PLAYER,
  true, // isSDCardInserted
  false, // isPlaying
  false, // isMuted
  false, // isBluetoothConnected
  50 // volume
};

static uint32_t lastBatteryCheck = 0;
static uint32_t lastClockUpdate = 0;
static uint32_t lastIdle = 0;
static bool blDim = 0;
// put function declarations here:
int myFunction(int, int);

void setup() {
  // put your setup code here, to run once:
  audioSetup();
  Wire.begin(I2C_SCL);
  int result = myFunction(2, 3);
  displaySplash();
  batterySetup();
  rtcSetup();
  inputSetup();
  sdCardInit();
  sdScanTracks();
  uiSetup();
  lastIdle = millis();
}

void loop() {
  // put your main code here, to run repeatedly:
  audioTick();
  uint32_t curr = millis();
  InputEvents event = inputRead();
  if (event != InputEvents::NONE){
    uiInputHandler(event);
    lastIdle = curr;
  }
  if (curr-lastBatteryCheck >= 60000){
    lastBatteryCheck = curr;
    BatteryStat batt = batteryRead();
  }
  uiDraw();
  uint32_t idle = curr - lastIdle;
  if (idle >= 60000 && !blDim) {
    backlightDim();
    blDim = true;
  }
  if (idle < 60000 && blDim) {
    backlightOn();
    blDim = false;
  }
}

// put function definitions here:
int myFunction(int x, int y) {
  return x + y;
}

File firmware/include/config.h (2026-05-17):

#pragma once 

#define SCREEN_W 320
#define SCREEN_H 240
#define TOP_BAR_H 20
#define AUDIO_CHANNELS 2
#define AUDIO_SAMPLE_RATE 44100
#define AUDIO_BUFFER_SIZE 512
#define AUDIO_BIT_DEPTH 16
#define SD_SPI_SPEED 40000000 // 40 Mhz
#define TFT_SPI_SPEED 40000000 // 40 Mhz
#define SCREEN_TIMEOUT 30000 // 30 seconds
#define IDLE_STANDBY 300000 // 5 minutes
#define INPUT_DEBOUNCE_DELAY 50 // 50 milliseconds
#define BLACK 0x0000
#define WHITE 0xFFFF
#define RED 0xF800
#define GREEN 0x07E0
#define BLUE 0x001F
#define YELLOW 0xFFE0
#define CYAN 0x07FF
#define MAGENTA 0xF81F
#define Gray 0xFFA9

#define BG_COLOR 0x18E3
#define TEXT_COLOR WHITE
#define COLOR_ACCENT 0x07E0
#define BATTERY_MAX_VOLTAGE 4.2
#define BATTERY_MIN_VOLTAGE 3.2
#define BATTERY_CRITICAL_VOLTAGE 3.0
#define BATTERY_WARNING_PERCENTAGE 20

#define BTN_LONG_PRESS 100

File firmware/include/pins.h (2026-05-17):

#pragma once

// tft
#define TFT_CS 10
#define TFT_MOSI 37
#define TFT_SCLK 36
#define TFT_RST 7
#define TFT_DC 9
#define TFT_MISO 35
#define TFT_BL 14

// sd card
#define SD_CS 11
#define SD_MOSI 37
#define SD_SCLK 36
#define SD_MISO 35

// i2s 
#define I2S_DOUT 13
#define I2S_BCLK 14
#define I2S_LRCLK 12

#define AMP_CS 11

// i2c
#define I2C_SCL 3
#define DS3231_ADDRESS 0x68
#define MGC3130_ADDRESS 0x42

#define MGC3130_RESET 6
#define MGC3130_TS 2

#define LED_CHG 1

#define BATTERY_ADC_PIN 18
#define BATTERY_CHG_PIN 39

#define SW3_PIN 15
#define SW4_PIN 16

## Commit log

2026-05-16 added audio setup play pause playing etc and in display i added starting boot text and error msgs
    [audio.cpp, display.cpp, main.cpp]
2026-05-16 added audio net/prev track shuffle repeat
2026-05-16 battery stats
2026-05-17 fix submit
    [BOM.csv, BOM.xlsx, battery.kicad_sch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]
